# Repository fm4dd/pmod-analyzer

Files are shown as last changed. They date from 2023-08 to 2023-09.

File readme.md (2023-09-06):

## PMOD Analyzer

### Description

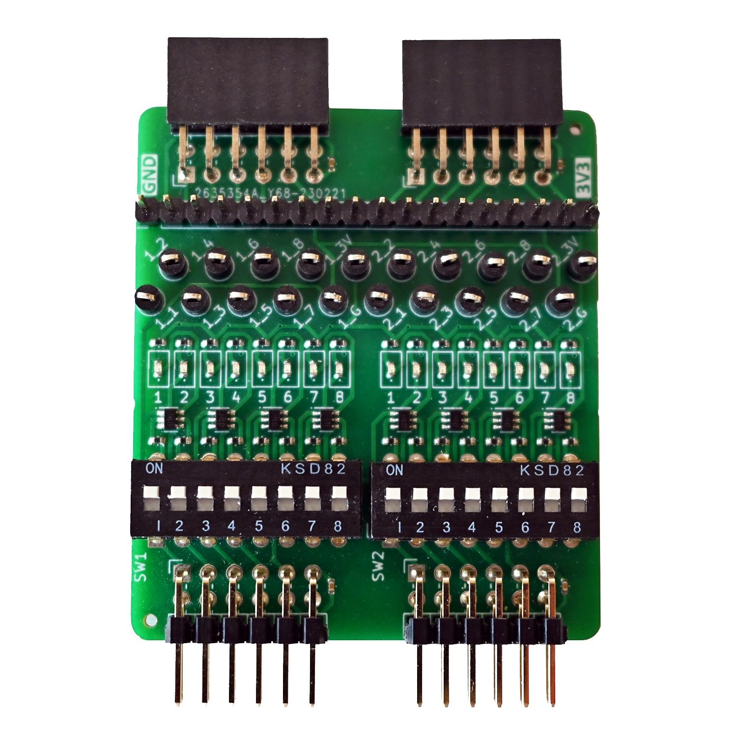
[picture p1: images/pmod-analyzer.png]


The PMOD Analyzer implements a twin-connector, pass-through PMOD board that routes 2x8 I/O signals from pinheader to pinsocket with breakout into a 18-pin 2.54mm header row for connecting protocol analyzers, and 20 test points for mini-grabber hook-ups that are useful for oscilloscope measurements. Lastly, each signal can be individually switched on to drive a control LED on each I/O line. This makes it ideal for troubleshooting by inserting it between a controller board and PMOD peripherals. With the LEDs switched on, the PMOD can operate "standalone" as a normal LED output board.

http://fpga.fm4dd.com/

### Schematic
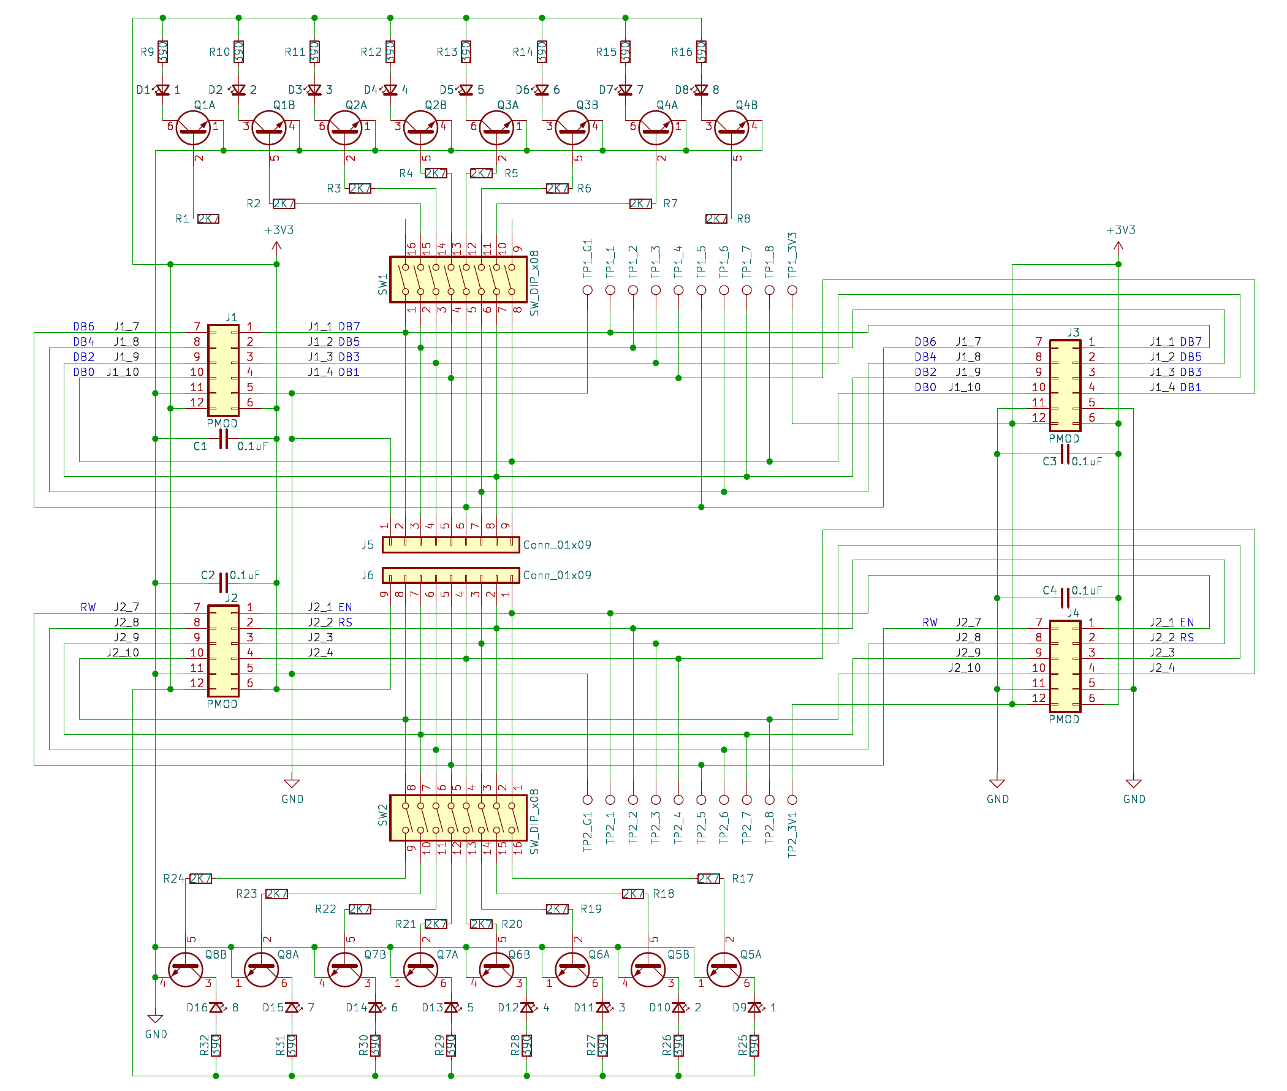
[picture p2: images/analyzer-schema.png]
PMOD Schematics


### PCB Gerber

| Version | Gerber | Schema |
|---|---|---|
| 1.0 |[20230218-pmod-analyzer-gerber.zip](fabfiles/v10/20230218-pmod-analyzer-gerber.zip) | [20230218-pmod-analyzer-schema.pdf](fabfiles/v10/20230218-pmod-analyzer-schema.pdf) |

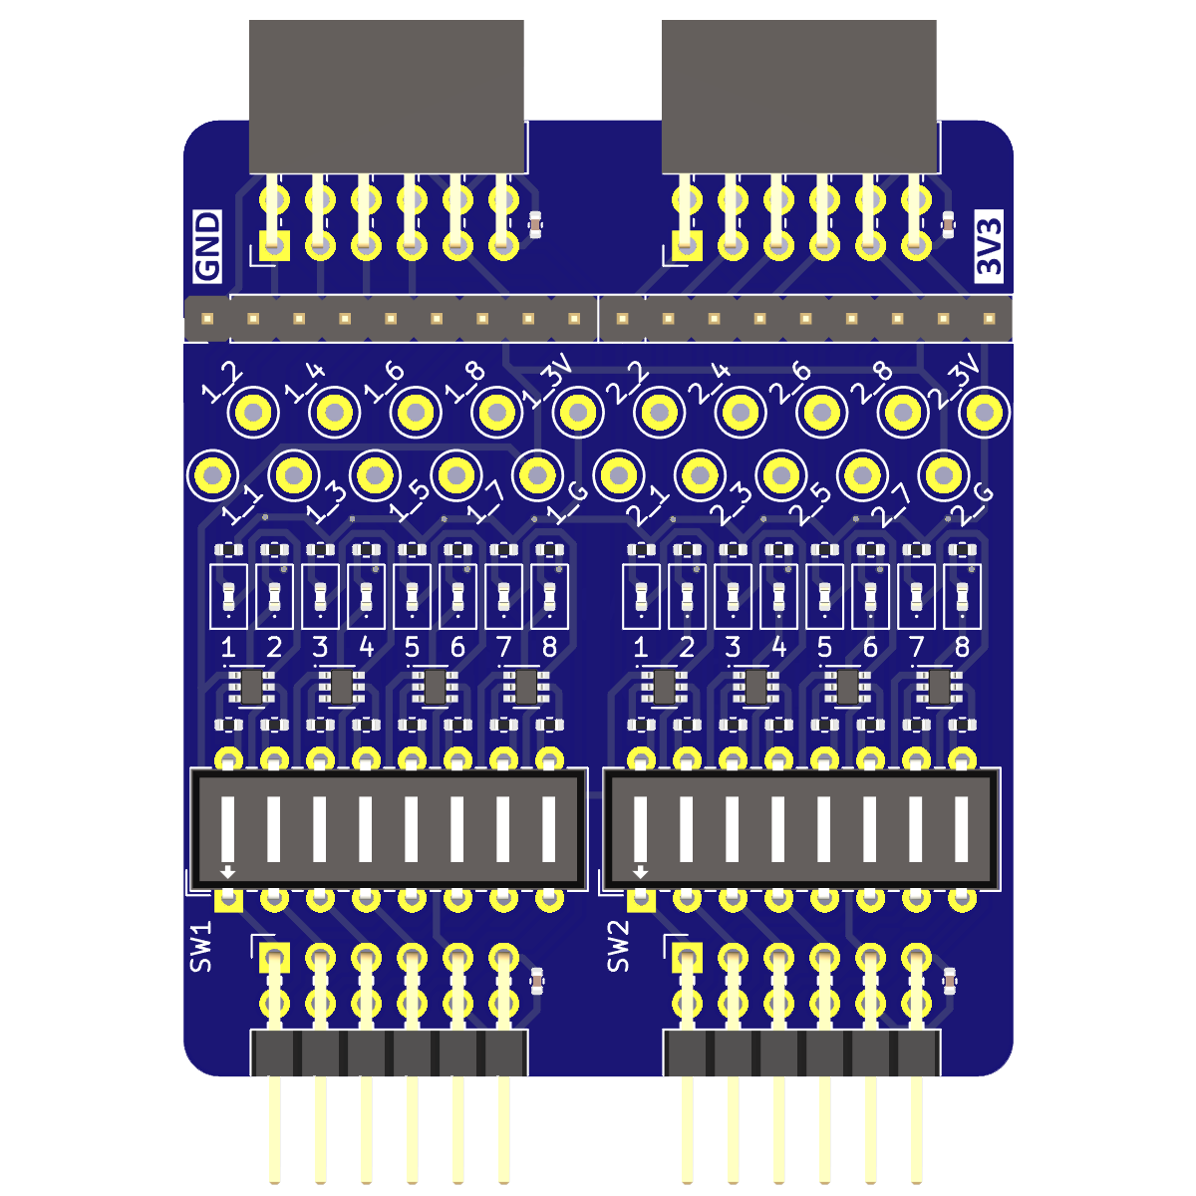
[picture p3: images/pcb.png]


### Board Pictures
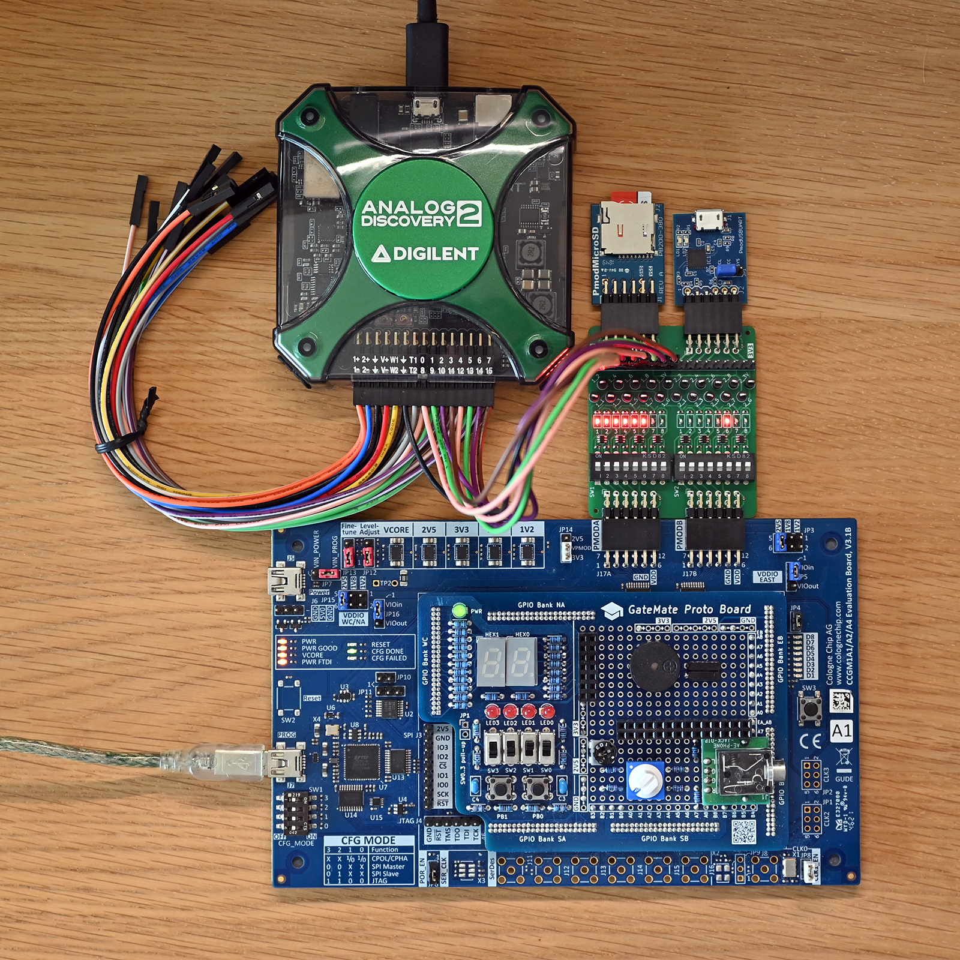
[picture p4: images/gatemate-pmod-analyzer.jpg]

PMOD Analyzer, connected to the Gatemate E1 FPGA board.

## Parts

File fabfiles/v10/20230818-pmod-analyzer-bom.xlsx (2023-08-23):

Comment | Designator | Footprint | JLCPCB Part #（optional）
0.1u C0402C103K4RECAUTO | C2,C3,C4,C1 | C_0402_1005Metric | C1525
red TJ-S1005SW4TGLC2R-A5 | D1,D2,D3,D4,D5,D6,D7,D8,D9,D10,D11,D12,D13,D14,D15,D16 | LED_0402_FPGA | C273598
PUMH10-115 | Q6,Q5,Q3,Q7,Q8,Q2,Q1,Q4 | SOT-363_SC-70-6 | C81379
2K7 | R4,R20,R2,R1,R21,R8,R24,R18,R6,R7,R3,R22,R5,R23,R17,R19 | R_0402_1005Metric | C25885
390R 0402WGF3900TCE | R11,R32,R10,R27,R28,R25,R13,R9,R26,R31,R30,R14,R29,R16,R12,R15 | R_0402_1005Metric | C25109

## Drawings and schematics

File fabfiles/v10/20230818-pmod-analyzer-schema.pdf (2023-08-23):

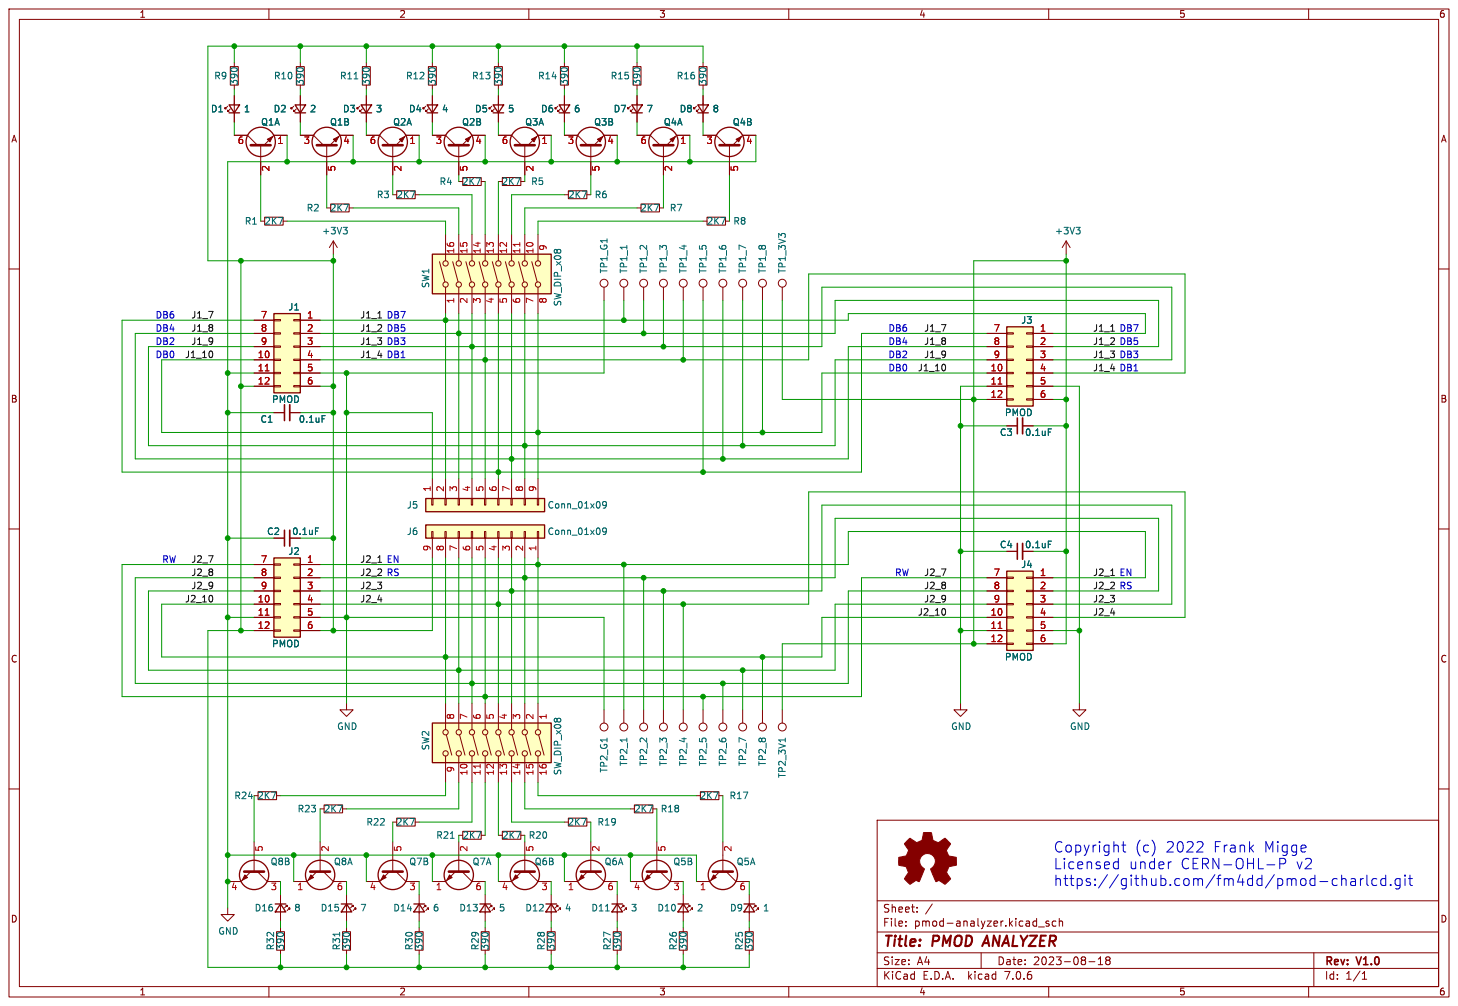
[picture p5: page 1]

https://github.com/fm4dd/pmod-charlcd.git

Id: 1/1 Title: PMOD ANALYZER

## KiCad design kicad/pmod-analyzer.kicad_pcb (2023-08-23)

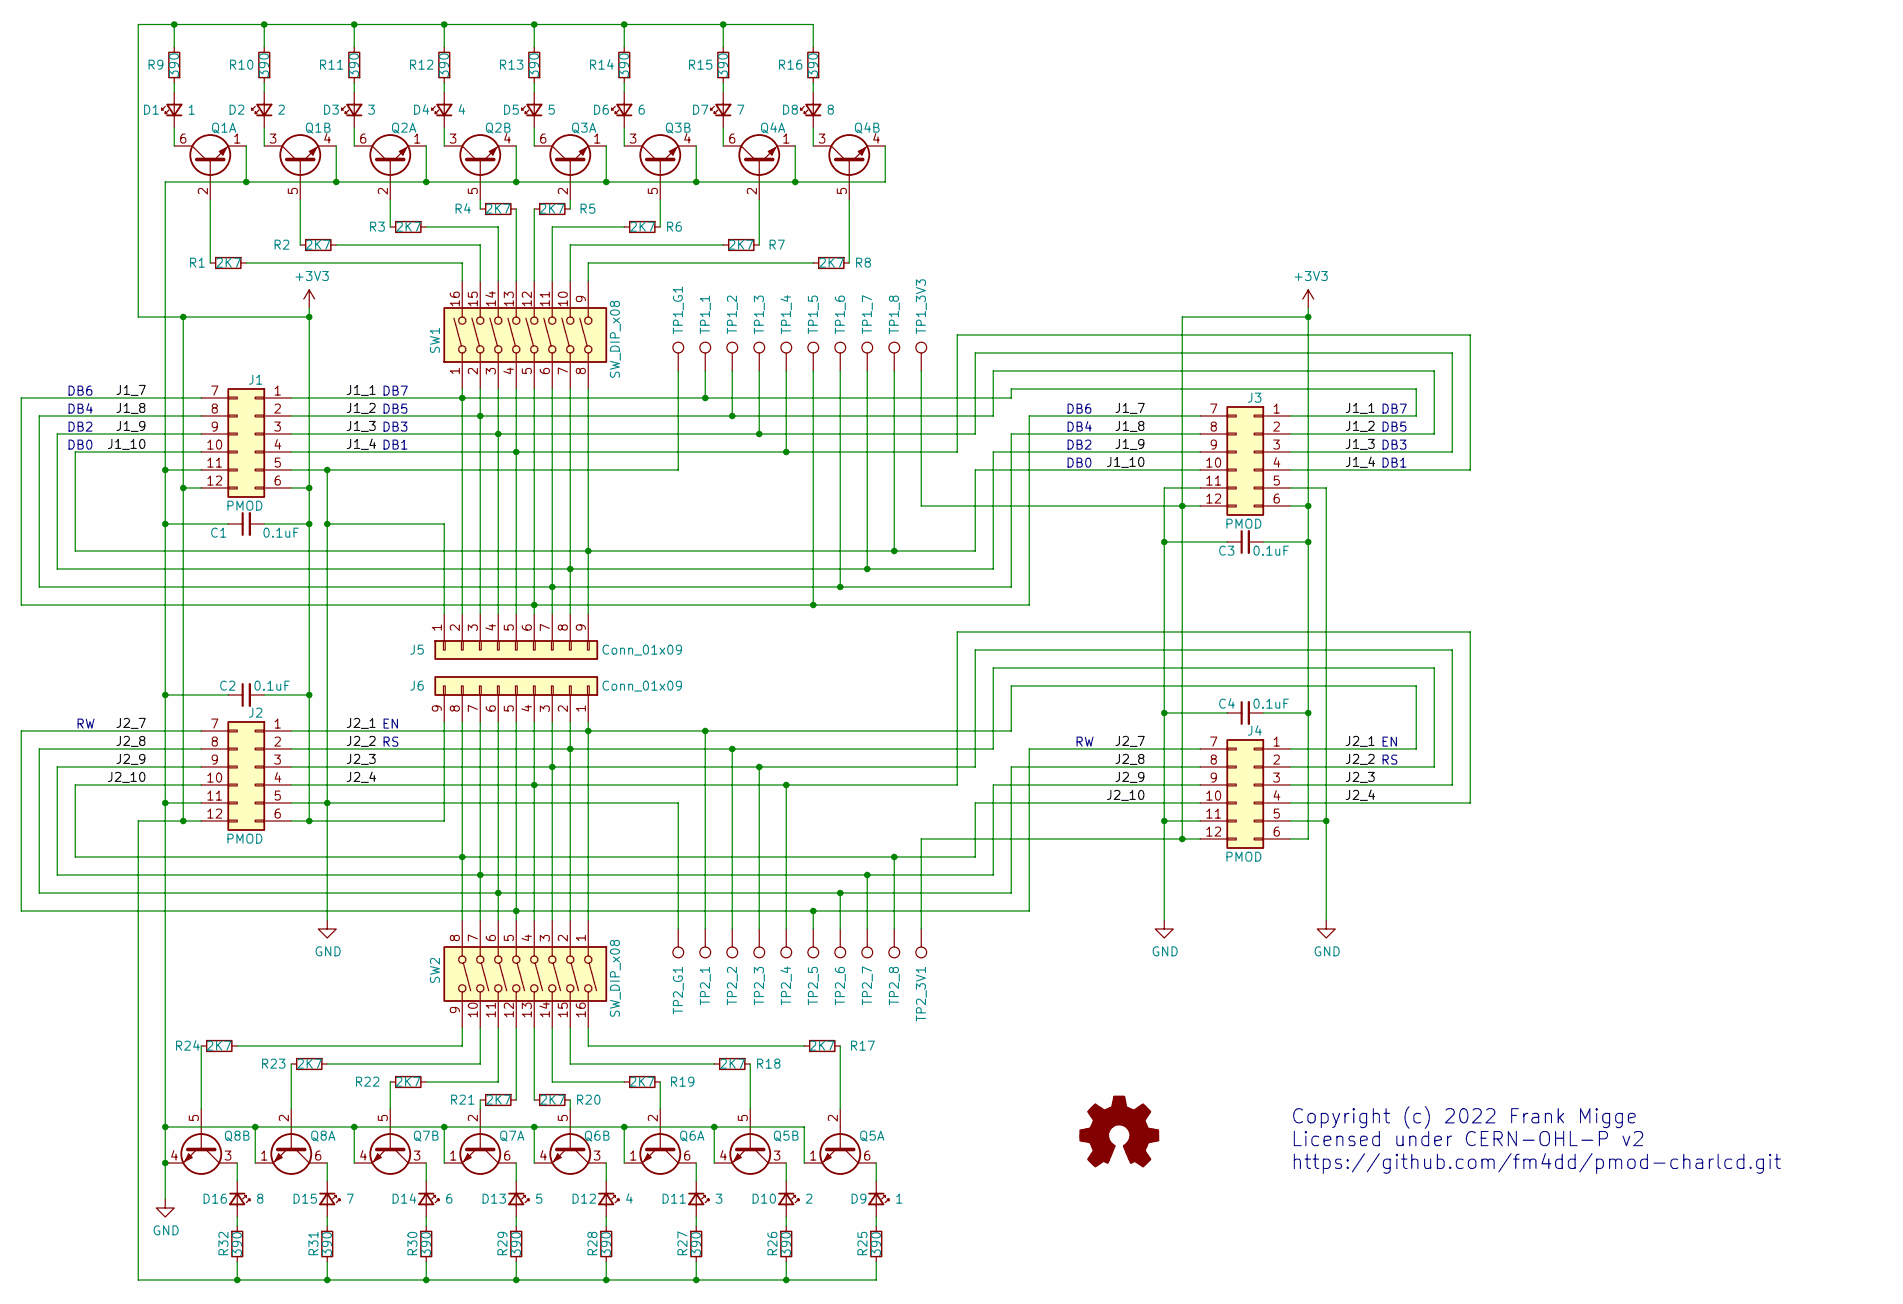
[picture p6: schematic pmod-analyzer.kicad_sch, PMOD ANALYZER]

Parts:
C1, C2, C3, C4: 0.1uF; C_0402_1005Metric
D1, D9: 1; LED_0402_FPGA
D2, D10: 2; LED_0402_FPGA
D3, D11: 3; LED_0402_FPGA
D4, D12: 4; LED_0402_FPGA
D5, D13: 5; LED_0402_FPGA
D6, D14: 6; LED_0402_FPGA
D7, D15: 7; LED_0402_FPGA
D8, D16: 8; LED_0402_FPGA
J1, J2: PMOD; PMODHeader_2x06_P2.54mm_Horizontal
J3, J4: PMOD; PMODPinSocket_2x06_P2.54mm_Horizontal
J5, J6: Conn_01x09; PinHeader_1x09_P2.54mm_Vertical
Q1, Q2, Q3, Q4, Q5, Q6, Q7, Q8: Q_Dual_NPN_NPN_E1B1C2E2B2C1; SOT-363_SC-70-6
R1, R2, R3, R4, R5, R6, R7, R8, R17, R18, R19, R20, R21, R22, R23, R24: 2K7; R_0402_1005Metric
R9, R10, R11, R12, R13, R14, R15, R16, R25, R26, R27, R28, R29, R30, R31, R32: 390; R_0402_1005Metric
SW1, SW2: SW_DIP_x08; SW_DIP_SPSTx08_Slide_6.7x21.88mm_W7.62mm_P2.54mm_LowProfile
TP1_1: 1_1; TestPoint_Keystone_5000-5004_Miniature
TP1_2: 1_2; TestPoint_Keystone_5000-5004_Miniature
TP1_3: 1_3; TestPoint_Keystone_5000-5004_Miniature
TP1_3V3: 1_3V; TestPoint_Keystone_5000-5004_Miniature
TP1_4: 1_4; TestPoint_Keystone_5000-5004_Miniature
TP1_5: 1_5; TestPoint_Keystone_5000-5004_Miniature
TP1_6: 1_6; TestPoint_Keystone_5000-5004_Miniature
TP1_7: 1_7; TestPoint_Keystone_5000-5004_Miniature
TP1_8: 1_8; TestPoint_Keystone_5000-5004_Miniature
TP1_G1: 1_G; TestPoint_Keystone_5000-5004_Miniature
TP2_1: 2_1; TestPoint_Keystone_5000-5004_Miniature
TP2_2: 2_2; TestPoint_Keystone_5000-5004_Miniature
TP2_3: 2_3; TestPoint_Keystone_5000-5004_Miniature
TP2_3V1: 2_3V; TestPoint_Keystone_5000-5004_Miniature
TP2_4: 2_4; TestPoint_Keystone_5000-5004_Miniature
TP2_5: 2_5; TestPoint_Keystone_5000-5004_Miniature
TP2_6: 2_6; TestPoint_Keystone_5000-5004_Miniature
TP2_7: 2_7; TestPoint_Keystone_5000-5004_Miniature
TP2_8: 2_8; TestPoint_Keystone_5000-5004_Miniature
TP2_G1: 2_G; TestPoint_Keystone_5000-5004_Miniature

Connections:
+3V3: C1.2, C2.2, C3.2, C4.2, J1.6, J1.12, J2.6, J2.12, J3.6, J3.12, J4.6, J4.12, J6.9, R9.2, R10.2, R11.2, R12.2, R13.2, R14.2, R15.2, R16.2, R25.2, R26.2, R27.2, R28.2, R29.2, R30.2, R31.2, R32.2, TP1_3V3.1, TP2_3V1.1
/J1_1: J1.1, J3.1, J5.2, SW1.1, TP1_1.1
/J1_2: J1.2, J3.2, J5.3, SW1.2, TP1_2.1
/J1_3: J1.3, J3.3, J5.4, SW1.3, TP1_3.1
/J1_4: J1.4, J3.4, J5.5, SW1.4, TP1_4.1
/J1_7: J1.7, J3.7, J5.6, SW1.5, TP1_5.1
/J1_8: J1.8, J3.8, J5.7, SW1.6, TP1_6.1
/J1_9: J1.9, J3.9, J5.8, SW1.7, TP1_7.1
/J1_10: J1.10, J3.10, J5.9, SW1.8, TP1_8.1
/J2_1: J2.1, J4.1, J6.1, SW2.1, TP2_1.1
/J2_2: J2.2, J4.2, J6.2, SW2.2, TP2_2.1
/J2_3: J2.3, J4.3, J6.3, SW2.3, TP2_3.1
/J2_4: J2.4, J4.4, J6.4, SW2.4, TP2_4.1
/J2_7: J2.7, J4.7, J6.5, SW2.5, TP2_5.1
/J2_8: J2.8, J4.8, J6.6, SW2.6, TP2_6.1
/J2_9: J2.9, J4.9, J6.7, SW2.7, TP2_7.1
/J2_10: J2.10, J4.10, J6.8, SW2.8, TP2_8.1
GND: C1.1, C2.1, C3.1, C4.1, J1.5, J1.11, J2.5, J2.11, J3.5, J3.11, J4.5, J4.11, J5.1, Q1.1 (E1), Q1.4 (E2), Q2.1 (E1), Q2.4 (E2), Q3.1 (E1), Q3.4 (E2), Q4.1 (E1), Q4.4 (E2), Q5.1 (E1), Q5.4 (E2), Q6.1 (E1), Q6.4 (E2), Q7.1 (E1), Q7.4 (E2), Q8.1 (E1), Q8.4 (E2), TP1_G1.1, TP2_G1.1
unnamed: D1.2 (A), R9.1
unnamed: D1.1 (K), Q1.6 (C1)
unnamed: D2.2 (A), R10.1
unnamed: D2.1 (K), Q1.3 (C2)
unnamed: D3.2 (A), R11.1
unnamed: D3.1 (K), Q2.6 (C1)
unnamed: D4.2 (A), R12.1
unnamed: D4.1 (K), Q2.3 (C2)
unnamed: D5.2 (A), R13.1
unnamed: D5.1 (K), Q3.6 (C1)
unnamed: D6.2 (A), R14.1
unnamed: D6.1 (K), Q3.3 (C2)
unnamed: D7.2 (A), R15.1
unnamed: D7.1 (K), Q4.6 (C1)
unnamed: D8.2 (A), R16.1
unnamed: D8.1 (K), Q4.3 (C2)
unnamed: D9.2 (A), R25.1
unnamed: D9.1 (K), Q5.6 (C1)
unnamed: D10.2 (A), R26.1
unnamed: D10.1 (K), Q5.3 (C2)
unnamed: D11.2 (A), R27.1
unnamed: D11.1 (K), Q6.6 (C1)
unnamed: D12.2 (A), R28.1
unnamed: D12.1 (K), Q6.3 (C2)
unnamed: D13.2 (A), R29.1
unnamed: D13.1 (K), Q7.6 (C1)
unnamed: D14.2 (A), R30.1
unnamed: D14.1 (K), Q7.3 (C2)
unnamed: D15.2 (A), R31.1
unnamed: D15.1 (K), Q8.6 (C1)
unnamed: D16.2 (A), R32.1
unnamed: D16.1 (K), Q8.3 (C2)
unnamed: Q1.2 (B1), R1.2
unnamed: Q1.5 (B2), R2.1
unnamed: Q2.2 (B1), R3.2
unnamed: Q2.5 (B2), R4.1
unnamed: Q3.2 (B1), R5.2
unnamed: Q3.5 (B2), R6.1
unnamed: Q4.2 (B1), R7.2
unnamed: Q4.5 (B2), R8.1
unnamed: Q5.2 (B1), R17.2
unnamed: Q5.5 (B2), R18.1
unnamed: Q6.2 (B1), R19.2
unnamed: Q6.5 (B2), R20.1
unnamed: Q7.2 (B1), R21.2
unnamed: Q7.5 (B2), R22.1
unnamed: Q8.2 (B1), R23.2
unnamed: Q8.5 (B2), R24.1
unnamed: R1.1, SW1.16
unnamed: R2.2, SW1.15
unnamed: R3.1, SW1.14
unnamed: R4.2, SW1.13
unnamed: R5.1, SW1.12
unnamed: R6.2, SW1.11
unnamed: R7.1, SW1.10
unnamed: R8.2, SW1.9
unnamed: R17.1, SW2.16
unnamed: R18.2, SW2.15
unnamed: R19.1, SW2.14
unnamed: R20.2, SW2.13
unnamed: R21.1, SW2.12
unnamed: R22.2, SW2.11
unnamed: R23.1, SW2.10
unnamed: R24.2, SW2.9

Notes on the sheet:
DB0
DB1
DB2
DB4
DB7
Copyright (c) 2022 Frank Migge Licensed under CERN-OHL-P v2 https://github.com/fm4dd/pmod-charlcd.git
DB6
DB3
DB5

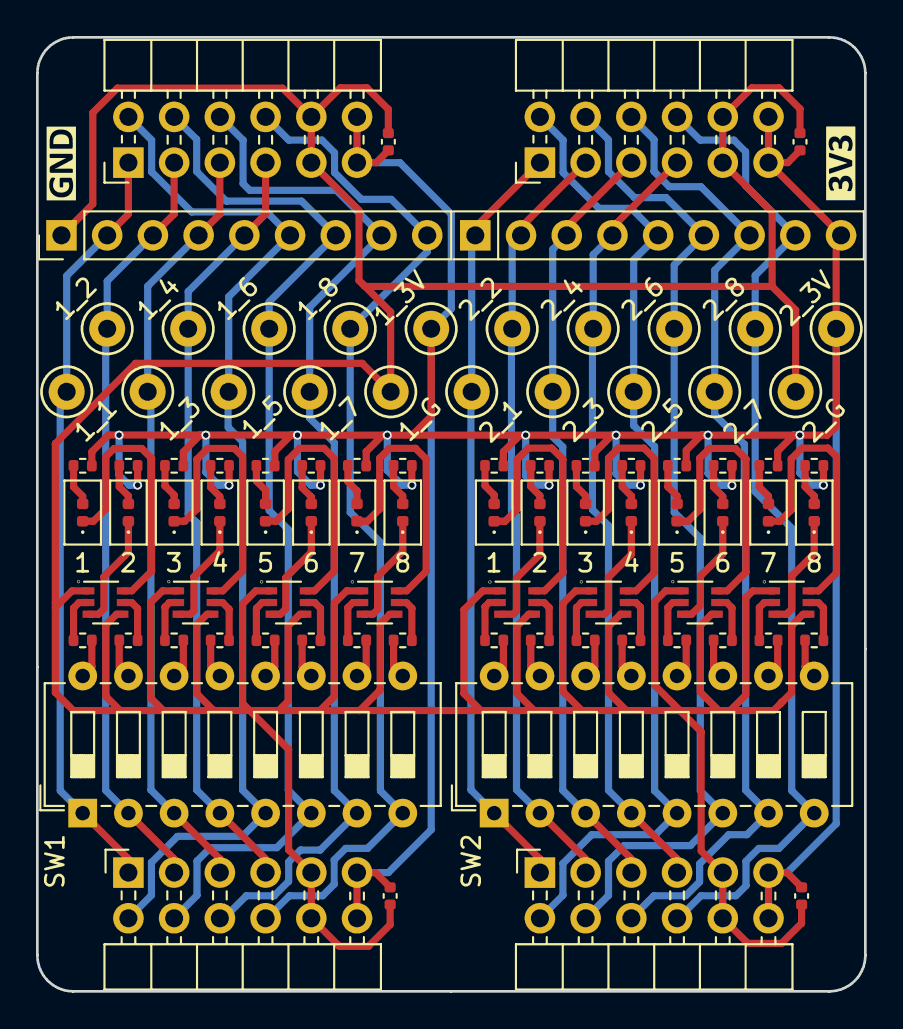
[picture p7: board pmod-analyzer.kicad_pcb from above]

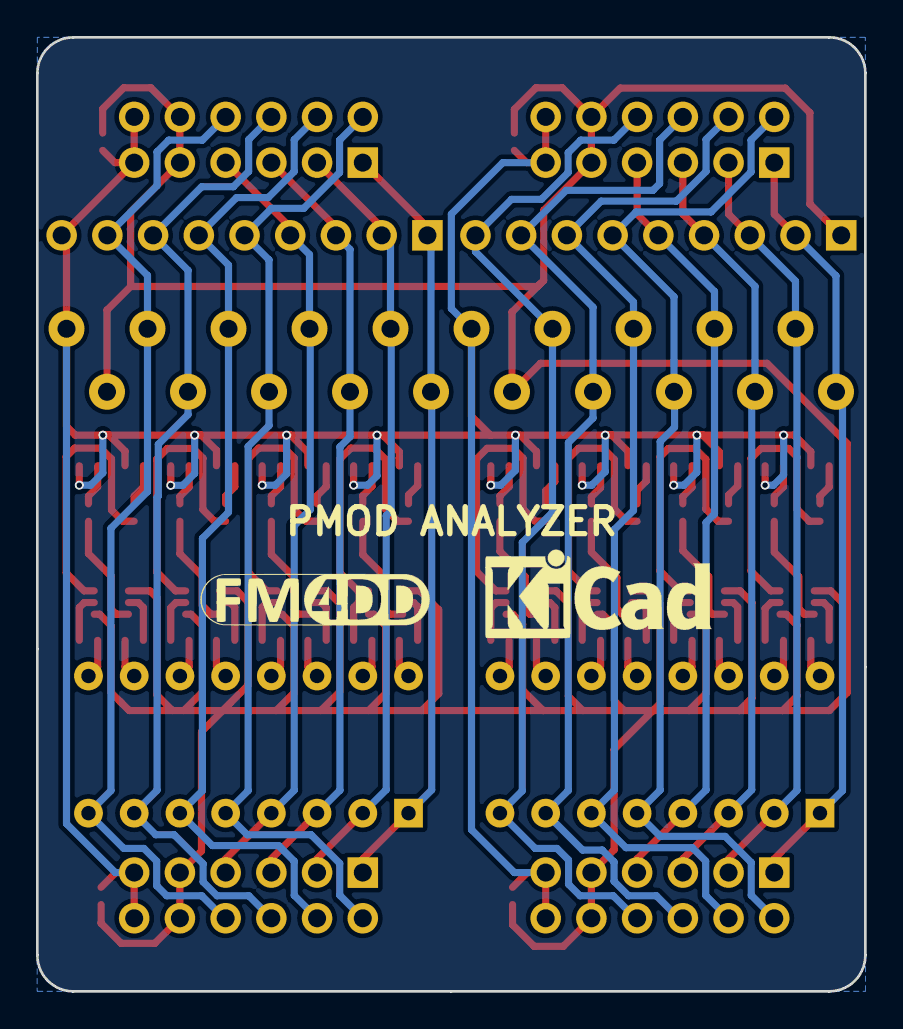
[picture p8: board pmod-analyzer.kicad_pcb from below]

Board: 2 copper layers, 46.0 x 53.0 mm, 90 parts (2 on the bottom side), 82 nets.

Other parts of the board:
Ref**: 1; Logo_FM4DD_5mm_SScr
Ref**#2: Logo_KiCad_5mm_SScr

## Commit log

2023-08-23 initial check-in
    [20230818-pmod-analyzer-bom.xlsx, pmod-analyzer.kicad_pcb, pmod-analyzer.kicad_sch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]
2023-09-06 add device SVG for documentations

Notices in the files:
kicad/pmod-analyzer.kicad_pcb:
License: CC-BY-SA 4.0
